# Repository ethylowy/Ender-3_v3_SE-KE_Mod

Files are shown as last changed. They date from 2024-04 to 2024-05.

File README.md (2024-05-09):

# ;TLDR
This profile will work on stock printer running Klipper - You don't need to mod anything. Just choose right settings. 

# DISCLAIMER
This is a new adventure in 3D Printing for me, as I moved from Artillery Hornet (quite modded actually) to a bit better Ender3 v3 SE.<br>
Many thanks to everyone, who contributed, and helped me with setting profiles and tweaking stuff.<br>
Some of my PrusaSlicer profile settings are based on Sims' work, which can be found here : https://github.com/suchmememanyskill/PrusaSlicer-Ender3-v3-SE-Config

# MODS  
One of the few mods i had done at the very beggining:  
<ol>
  <li>Installing Klipper on my Dell Wyse 3040 terminal, and connecting it to Ender</li>
  <li>Linear rail X-axis</li>
  <li>Linear rail Y-axis</li>
  <li>Ceramic hot-end swap from Creality K1 printer (so i can print TPU and other flex'es)</li>
  <li>Original Bowden inside Sprite extruder changed to Capricorn</li>
  <li>Cooling replacement for a central 40mm fan and 2nd one cooling off prints</li>
  <li>Reverse bowden tube and moving the filament spool out of Z-axis to the side of the printer - no more Z-axis wobble nad ability to print straight from drybox.</li>
</ol>  

# How it looks (it's dirty lol)
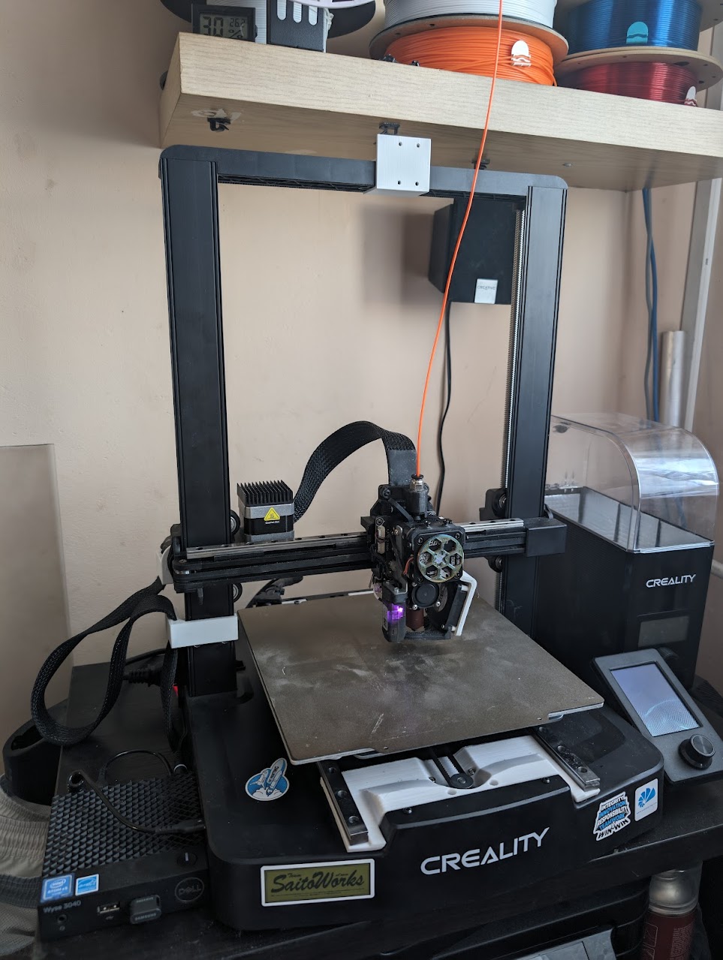
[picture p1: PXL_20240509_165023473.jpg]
My Ender-3 v3 SE


# HARDWARE
I used the hardware mostly available online, like AliExpress or Ebay.
<ul>
  <li>Creality K1 Hotend (bimetal heatbreak) https://aliexpress.com/item/1005005871367214.html</li>
  <li>Linear rail for X axis (choose 300mm with block) https://aliexpress.com/item/1005004226065107.html</li>
  <li>0.4 & 0.6 Hardened Steel Nozzle https://aliexpress.com/item/1005006590721284.html</li>
  <li>PEI magnetic bed surface https://pl.aliexpress.com/item/1005005832409431.html</li>
  <li>DELL Wyse 3040 (performance-wise its an RPi3B+ substitute) https://www.ebay.com/itm/196293394635</li>
  <li>Lightweight bed mounting replacement for fast printing https://pl.aliexpress.com/item/1005004351782508.html</li>
</ul>

# 3D PRINTABLE PARTS
<ul>
<li>X-axis linear mount - https://www.printables.com/pl/model/716958-linear-x-rail-mod-ender-3-v3-se/files</li>
<li>Y-axis linear mount - https://makerworld.com/en/models/239219#profileId-255056</li>
</ul>

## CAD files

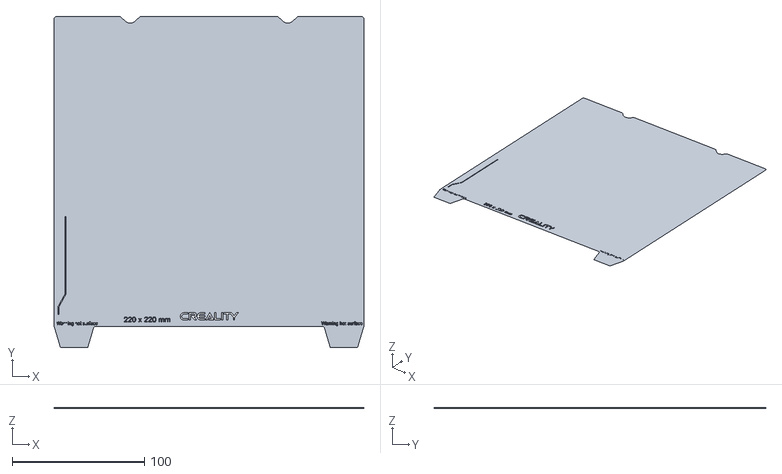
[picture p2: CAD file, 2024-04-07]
PrusaSlicer profile/printer/E 3 v3 SE.stl
234.0 x 250.0 x 0.01

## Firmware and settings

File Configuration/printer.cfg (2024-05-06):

# STM32F103
#"28KiB bootloader"
#serial (on USART1 PA10/PA9)
#"Enable extra low-leverl configuration options"
#"Disable SWD on startup"
##################################################################
# INCLUDES
##################################################################
[include start.cfg]
[include end.cfg]
[include display.cfg]
[include input_shaper.cfg]
[include mainsail.cfg]
[include filament.cfg]
[include macros.cfg]
#[include adxl.cfg]

##################################################################
# PRINTER CONFIGURATION Ender-3 v3 SE by Ethylowy
##################################################################
[mcu]
serial: /dev/serial/by-id/usb-1a86_USB_Serial-if00-port0
restart_method: command

[printer]
kinematics: cartesian
max_velocity: 500
max_accel: 3500
max_z_velocity: 50
max_z_accel: 500
square_corner_velocity: 5.0

[force_move]
enable_force_move: True

[temperature_sensor mcu_temp]
sensor_type: temperature_mcu
min_temp: 0
max_temp: 100

[virtual_sdcard]
path: ~/printer_data/gcodes
on_error_gcode: CANCEL_PRINT

[output_pin beeper]
pin: PB0

[output_pin MainBoardFan]
pin: !PB1

[gcode_arcs]
resolution: 0.5

[respond]

[exclude_object]

[skew_correction]

##################################################################
# STEPPERS
##################################################################
[stepper_x]
step_pin: PC2
dir_pin: !PB9
enable_pin: !PC3
microsteps: 64
rotation_distance: 40
endstop_pin: ^!PA5
position_endstop: -6
position_min: -6
position_max: 230
homing_speed: 50

[tmc2209 stepper_x]
uart_pin: PB12
run_current: 0.60
sense_resistor: 0.150
stealthchop_threshold: 0
interpolate: false

[stepper_y]
step_pin: PB8
dir_pin: PB7
enable_pin: !PC3
microsteps: 64
rotation_distance: 40
endstop_pin: !PA6
position_endstop: -14
position_min: -14
position_max: 230
homing_speed: 50

[tmc2209 stepper_y]
uart_pin: PB13
run_current: 0.60
sense_resistor: 0.150
stealthchop_threshold: 0
interpolate: false

[stepper_z]
step_pin: PB6
dir_pin: !PB5
enable_pin: !PC3
microsteps: 16
rotation_distance: 8
endstop_pin: probe:z_virtual_endstop
position_min: -3
position_max: 240
homing_speed: 10
second_homing_speed: 2

[tmc2209 stepper_z]
uart_pin: PB14
run_current: 0.8
sense_resistor: 0.150
stealthchop_threshold: 0
interpolate: false

##################################################################
# Extruder & hotend configuration
##################################################################
[extruder]
max_extrude_only_distance: 105.0
step_pin: PB4
dir_pin: PB3
enable_pin: !PC3
microsteps: 16
rotation_distance: 7.53
nozzle_diameter: 0.400
filament_diameter: 1.750
heater_pin: PA1
sensor_type: EPCOS 100K B57560G104F
sensor_pin: PC5
min_temp: 0
max_temp: 310

[firmware_retraction]
retract_length: 0.6
retract_speed: 75
unretract_extra_length: 0
unretract_speed: 60

[verify_heater extruder]
check_gain_time: 200
hysteresis: 5

[heater_fan hotend_fan]
pin: PC1
max_power: 1.0
shutdown_speed : 0
cycle_time: 0.010
hardware_pwm: false
kick_start_time: 0.100
off_below: 0.0
heater:extruder
heater_temp : 50
fan_speed : 1.0

[fan]
pin: PA0

##################################################################
# Bed & leveling configuration
##################################################################
[heater_bed]
heater_pin: PB2
sensor_type: EPCOS 100K B57560G104F
sensor_pin: PC4
min_temp: 0
max_temp: 110

[verify_heater heater_bed]
check_gain_time: 120
heating_gain: 1.0
hysteresis: 10

[bltouch]
sensor_pin: ^PC14
control_pin: PC13
x_offset: -24.0
y_offset: -13.0
#z_offset: 0.1
speed: 20
pin_move_time: 0.4
stow_on_each_sample: False
probe_with_touch_mode: True
lift_speed:20

[safe_z_home]
home_xy_position: 134,123
speed: 50
z_hop: 10
z_hop_speed: 5

[bed_mesh]
speed: 120
horizontal_move_z: 5
mesh_min: 30,30
mesh_max: 205,215.5
probe_count: 5,5
algorithm: bicubic

# [filament_switch_sensor spool]
# pause_on_runout: True
# switch_pin: ^!PA6

##################################################################
# CANCEL PRINT
##################################################################
[gcode_macro CANCEL_PRINT]
rename_existing: BASE_CANCEL_PRINT
gcode:
    SET_IDLE_TIMEOUT TIMEOUT={printer.configfile.settings.idle_timeout.timeout} ; set timeout back to configured value
    CLEAR_PAUSE
    PRINT_END
    BASE_CANCEL_PRINT

#*# <---------------------- SAVE_CONFIG ---------------------->
#*# DO NOT EDIT THIS BLOCK OR BELOW. The contents are auto-generated.
#*#
#*# [heater_bed]
#*# control = pid
#*# pid_kp = 65.091
#*# pid_ki = 0.871
#*# pid_kd = 1215.566
#*#
#*# [extruder]
#*# control = pid
#*# pid_kp = 25.634
#*# pid_ki = 2.136
#*# pid_kd = 76.901
#*#
#*# [bltouch]
#*# z_offset = 2.210
#*#
#*# [skew_correction default]
#*# xy_skew = -0.002828860100808275
#*# xz_skew = 0.0
#*# yz_skew = 0.0
#*#
#*# [bed_mesh default]
#*# version = 1
#*# points =
#*# 	  0.682500, 0.385000, 0.202500, 0.027500, 0.087500
#*# 	  0.475000, 0.187500, 0.025000, -0.120000, -0.080000
#*# 	  0.330000, 0.070000, -0.102500, -0.250000, -0.190000
#*# 	  0.200000, -0.070000, -0.212500, -0.342500, -0.277500
#*# 	  0.135000, -0.142500, -0.307500, -0.432500, -0.375000
#*# x_count = 5
#*# y_count = 5
#*# mesh_x_pps = 2
#*# mesh_y_pps = 2
#*# algo = bicubic
#*# tension = 0.2
#*# min_x = 30.0
#*# max_x = 205.0
#*# min_y = 30.0
#*# max_y = 215.48

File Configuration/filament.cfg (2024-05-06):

[gcode_macro ERYONE_SILK_PLA]
gcode:
  SET_PRESSURE_ADVANCE ADVANCE=0.089

[gcode_macro ERYONE_PETG]
gcode:
  SET_PRESSURE_ADVANCE ADVANCE=0.116

[gcode_macro OVERTURE_PETG]
gcode:
  SET_PRESSURE_ADVANCE ADVANCE=0.170

[gcode_macro GENERIC_PLA]
gcode:
  SET_PRESSURE_ADVANCE ADVANCE=0.023

[gcode_macro GENERIC_NYLON]
gcode:
  SET_PRESSURE_ADVANCE ADVANCE=0.104

[gcode_macro ROSA_ASA]
gcode:
  SET_PRESSURE_ADVANCE ADVANCE=0.092

[gcode_macro CR_ABS]
gcode:
  SET_PRESSURE_ADVANCE ADVANCE=0.071

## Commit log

2024-04-05 Little tidy-up
    [adxl.cfg, display.cfg, end.cfg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]
2024-04-06 tweaked retraction settings
    [printer.cfg]
2024-04-06 updated configs
    [display.cfg, end.cfg, macros.cfg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]
2024-04-06 Added filament macros
    [filament.cfg, start.cfg]
2024-04-07 Added PrusaSlicer profile
    [E 3 v3 SE.stl]
2024-04-07 Cleaning the code
    removed malicious Z offset setting and shortening the overall macro code
    [start.cfg]
2024-04-07 added ASA filament
    [filament.cfg]
2024-04-09 Added PA optimised filaments
2024-04-09 Replaced printer profile
2024-04-09 Updated Klipper config file for Ender
    [end.cfg, filament.cfg, macros.cfg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]
2024-04-12 Tweaked printer.cfg
    [printer.cfg]
2024-04-26 Updated files for speeds ~250mm/s
2024-05-04 Added new firmware and filament
